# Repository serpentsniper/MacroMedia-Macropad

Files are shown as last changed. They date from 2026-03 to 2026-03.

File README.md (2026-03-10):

# MacroMedia

MacroMedia is a 9 key media macropad with a rotary encoder and an OLED display. It uses KMK firmware on CircuitPython and is built around the Seeed XIAO RP2040.

Built for the Hackpad YSWS through Hack Club Blueprint.

## Features:

* 3x3 key grid for media and productivity controls
* 128x32 OLED display showing an equaliser bars animation
* EC11 rotary encoder for volume control
* 3 layers: Media, DAW shortcuts, and System/Function keys
* Fully 3D printed case
* No LEDs — clean and simple build

## CAD Model:

The case is two pieces — a top plate and a bottom enclosure. Everything is held together with 4 M3x16mm screws and M3x5x4mm heatset inserts.

---

Case

---

The top plate is 1.5mm thick at the switch cutouts so MX switches clip in securely. The encoder shaft and OLED display window are cut into the top section above the key grid.

Made in Autodesk Inventor.
---

Top Case

---

Bottom Case

---

## PCB:

Designed in KiCad. 2-layer board, 59.5mm x 100mm.

---

### Schematic
Schematic

---

### PCB
PCB

---

* 3x3 switch matrix with COL2ROW diode configuration
* Diodes on the back layer, tucked between switch rows
* XIAO RP2040 mounted on the bottom center with USB-C accessible from the rear
* OLED header top-left, encoder top-right
* Ground pour on B.Cu

## Firmware Overview:

This macropad uses [KMK](https://github.com/KMKfw/kmk_firmware) firmware running on CircuitPython.

IMPORTANT NOTE: This macropad's firmware also includes the adafruit\_ssd1306 to interact with the OLED screen. This must be installed into the lib folder on the RP2040.

---

### OLED Animation (concept preview)
Animation

---

### Key Mapping

**Layer 0 — Media:**

|Prev|Play/Pause|Next|
|-|-|-|
|Stop|Mute|Vol Up|
|Layer 1|Layer 2|Vol Down|

**Layer 1 — DAW:**

|Undo|Redo|Save|
|-|-|-|
|Cut|Copy|Paste|
|\_\_|\_\_|\_\_|

**Layer 2 — System:**

|F13|F14|F15|
|-|-|-|
|F16|F17|F18|
|\_\_|\_\_|Reset|

**Encoder:** Volume up/down on Layer 0, zoom on Layer 1, brightness on Layer 2.

## BOM:

* 9x Cherry MX Switches
* 9x DSA Keycaps
* 9x 1N4148 DO-35 Diodes
* 1x EC11 Rotary Encoder
* 1x 0.91" 128x32 OLED Display (GND-VCC-SCL-SDA pin order)
* 1x Seeed XIAO RP2040
* 4x M3x16mm Screws
* 4x M3x5x4mm Heatset Inserts
* 1x 3D Printed Case (2 parts: top plate + bottom enclosure)

## Setup:

1. Flash CircuitPython from https://circuitpython.org/board/seeeduino\_xiao\_rp2040
2. Copy `main.py` to your `CIRCUITPY` drive
3. Copy `adafruit\_ssd1306.mpy` to the lib folder in your `CIRCUITPY` drive (accessible at https://github.com/adafruit/Adafruit\_CircuitPython\_SSD1306)

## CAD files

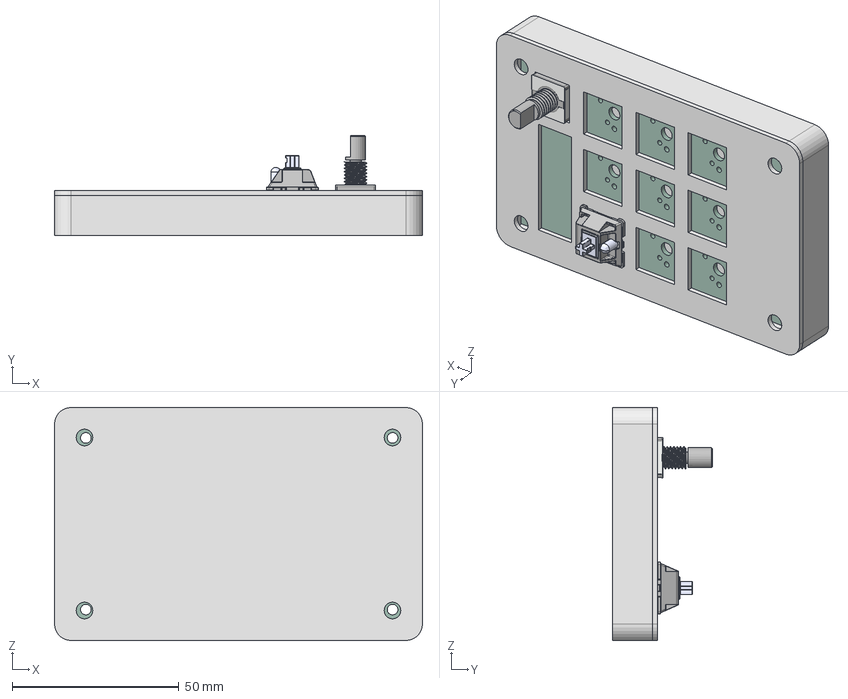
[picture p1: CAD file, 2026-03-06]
CAD/Complete_Hackpad.step
110.4 x 30.0 x 69.9 mm
top part
æè½¬ç¼ç å¨
MX Öá °´¼ü¡ä_¨¹ ___¡§1
MX ס סͥ¨¢¨¬_¡ §¡顧__
MXס ϞñLEDLEDLED
MXÖá ÖáÌå µ×²¿ ¦Ì¡ Á2__Ä¬ÈÏ_¨¢2____¨¨_
֫½ğ__Ĭɏ__¨¨_
D_DO-35_SOD27_P7.62mm_Horizontal x 9
hackpad_PCB

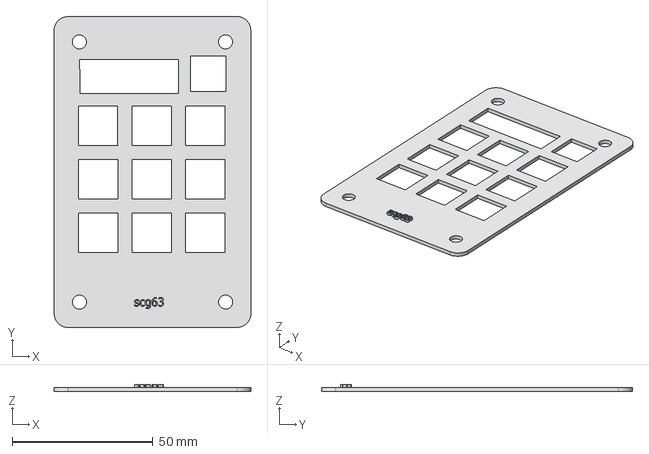
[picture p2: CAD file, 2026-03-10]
production/Top Part.step
69.9 x 110.4 x 2.50 mm

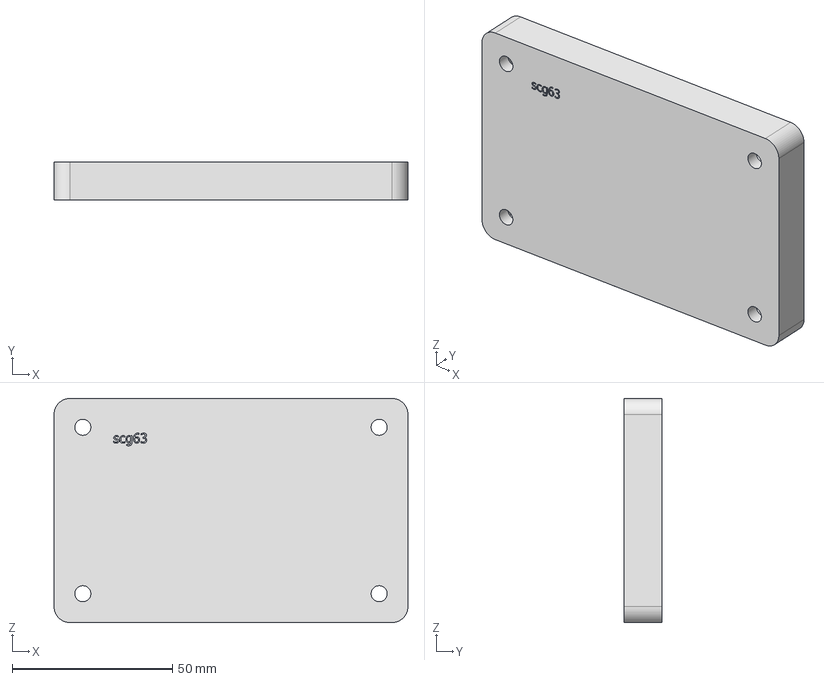
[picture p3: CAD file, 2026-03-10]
production/Bottom Part.step
110.4 x 12.0 x 69.9 mm

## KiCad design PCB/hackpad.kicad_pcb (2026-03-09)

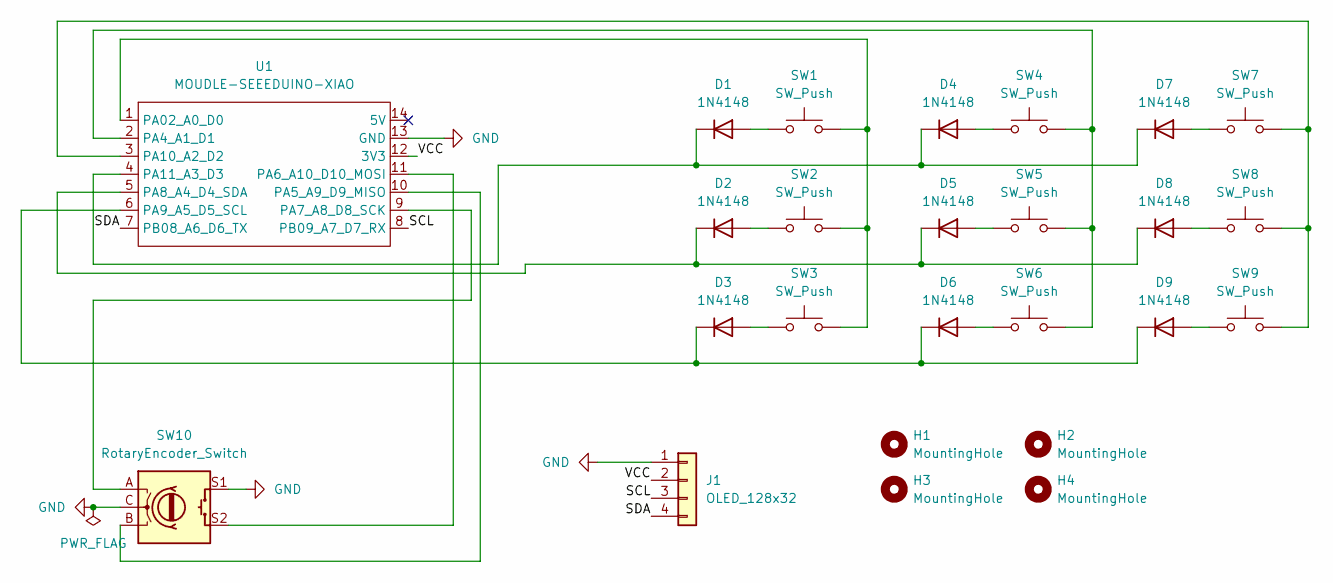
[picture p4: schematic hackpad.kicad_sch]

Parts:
D1, D2, D3, D4, D5, D6, D7, D8, D9: 1N4148; D_DO-35_SOD27_P7.62mm_Horizontal
H1, H2, H3, H4: MountingHole; MountingHole_3.2mm_M3
J1: OLED_128x32; SSD1306-0.91-OLED-4pin-128x32
SW1, SW2, SW3, SW4, SW5, SW6, SW7, SW8, SW9: SW_Push; SW_Cherry_MX_1.00u_PCB
SW10: RotaryEncoder_Switch; RotaryEncoder_Alps_EC11E-Switch_Vertical_H20mm
U1: MOUDLE-SEEEDUINO-XIAO; XIAO-Generic-Hybrid-14P-2.54-21X17.8MM

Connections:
/SCL: J1.3, U1.8 (PB09_A7_D7_RX)
/SDA: J1.4, U1.7 (PB08_A6_D6_TX)
/VCC: J1.2, U1.12 (3V3)
GND: J1.1, SW10.C, SW10.S1, U1.13 (GND)
unnamed: D1.2 (A), SW1.1
unnamed: D1.1 (K), D4.1 (K), D7.1 (K), U1.4 (PA11_A3_D3)
unnamed: D2.2 (A), SW2.1
unnamed: D2.1 (K), D5.1 (K), D8.1 (K), U1.5 (PA8_A4_D4_SDA)
unnamed: D3.2 (A), SW3.1
unnamed: D3.1 (K), D6.1 (K), D9.1 (K), U1.6 (PA9_A5_D5_SCL)
unnamed: D4.2 (A), SW4.1
unnamed: D5.2 (A), SW5.1
unnamed: D6.2 (A), SW6.1
unnamed: D7.2 (A), SW7.1
unnamed: D8.2 (A), SW8.1
unnamed: D9.2 (A), SW9.1
unnamed: SW1.2, SW2.2, SW3.2, U1.1 (PA02_A0_D0)
unnamed: SW4.2, SW5.2, SW6.2, U1.2 (PA4_A1_D1)
unnamed: SW10.B, U1.10 (PA5_A9_D9_MISO)
unnamed: SW10.S2, U1.11 (PA6_A10_D10_MOSI)
unnamed: SW10.A, U1.9 (PA7_A8_D8_SCK)
unnamed: SW7.2, SW8.2, SW9.2, U1.3 (PA10_A2_D2)

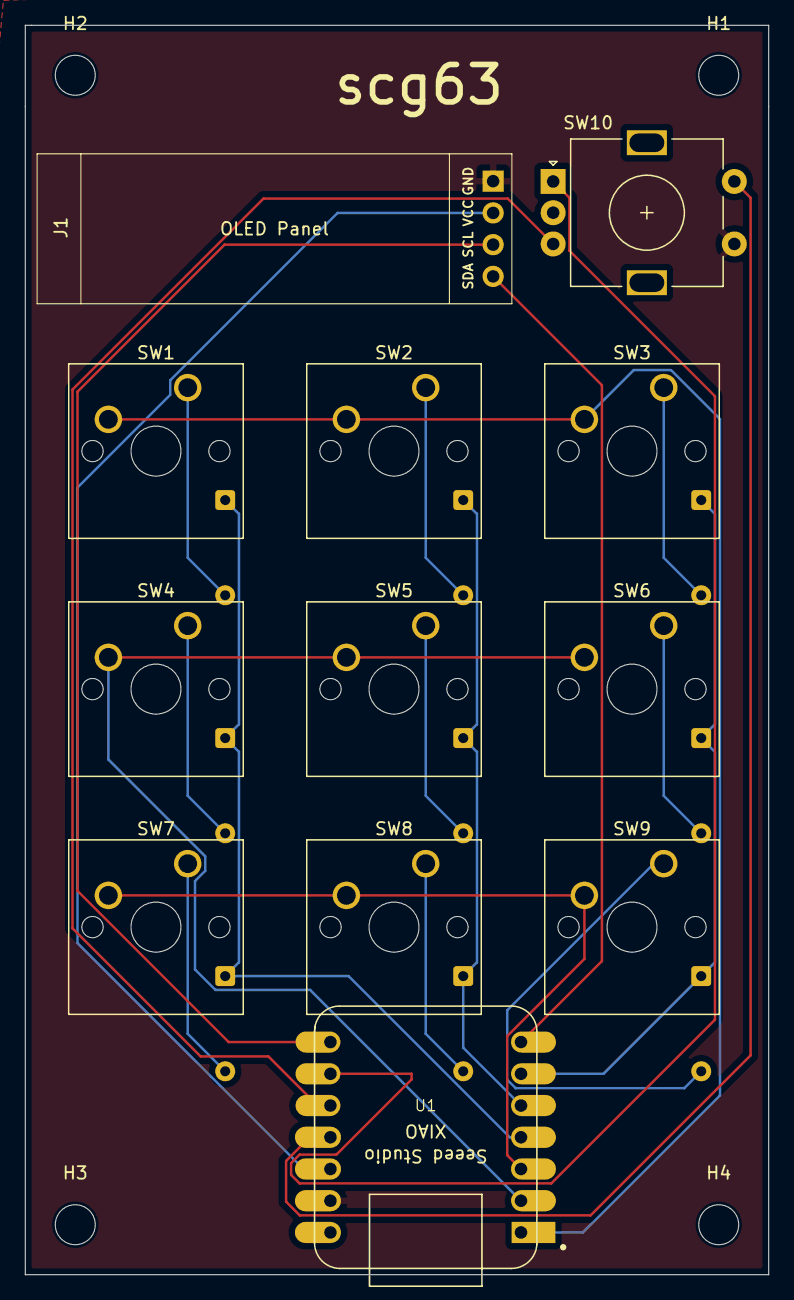
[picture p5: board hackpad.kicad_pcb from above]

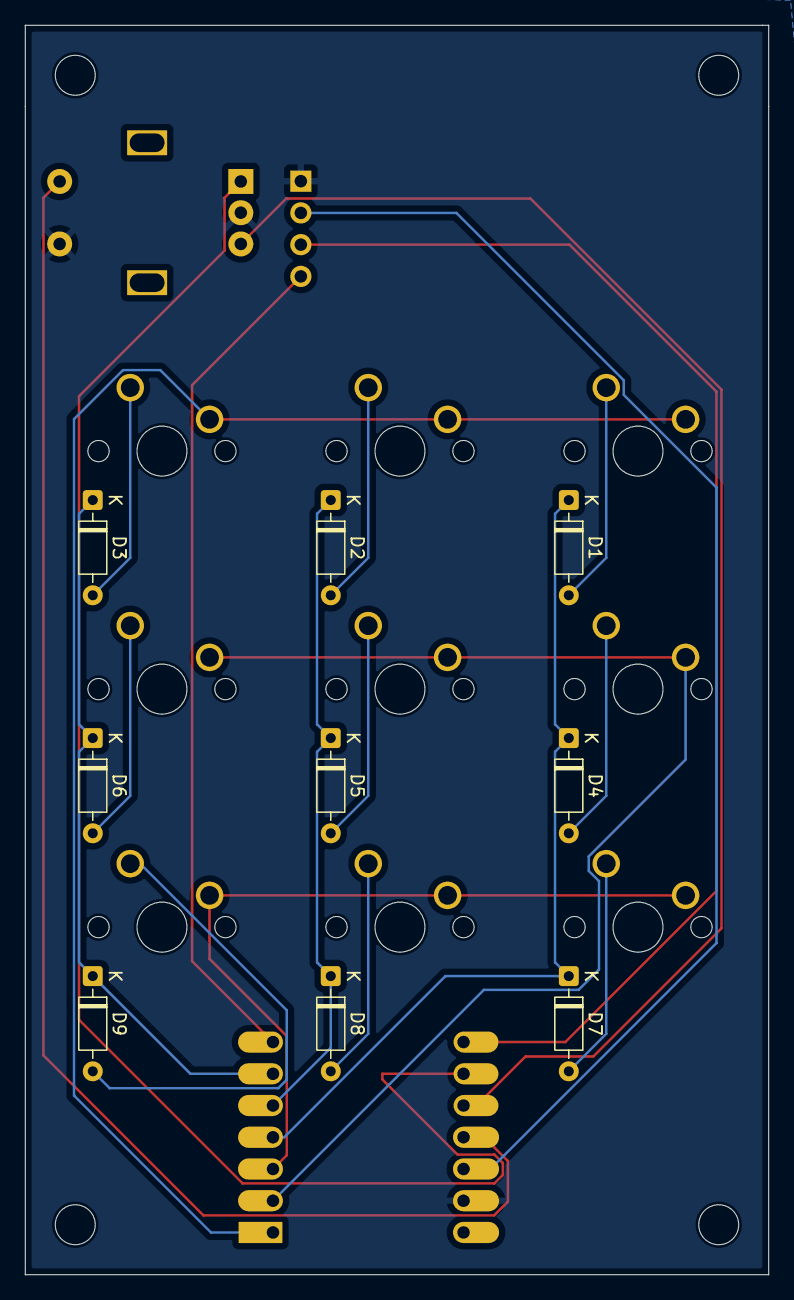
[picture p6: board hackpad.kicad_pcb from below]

Board: 2 copper layers, 59.5 x 100.0 mm, 25 parts (9 on the bottom side), 22 nets.

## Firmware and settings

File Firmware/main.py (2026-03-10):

"""
MelodyPad - 3x3 Music/Media Macropad Firmware
================================================
Hardware: Seeed XIAO RP2040 + 9 MX switches + 1 EC11 encoder + 0.91" OLED
Framework: KMK (CircuitPython)

Features:
  - 3-layer keymap (Media, DAW, System)
  - Rotary encoder for volume
  - Animated equalizer visualization on OLED
"""

import board
import busio
import digitalio
import random
import time

from kmk.kmk_keyboard import KMKKeyboard
from kmk.keys import KC
from kmk.scanners.keypad import MatrixScanner
from kmk.modules.layers import Layers
from kmk.modules.encoder import EncoderHandler
from kmk.modules.media_keys import MediaKeys
from kmk.extensions import Extension

# ============================================================
# OLED EQUALIZER EXTENSION
# ============================================================

import adafruit_ssd1306

class OledEqualizer(Extension):
    """Custom KMK extension that draws a randomized music
    equalizer animation on a 128x32 SSD1306 OLED."""

    def __init__(self, i2c, num_bars=16, bar_width=6, gap=2,
                 update_interval=0.05):
        self.i2c = i2c
        self.num_bars = num_bars
        self.bar_width = bar_width
        self.gap = gap
        self.update_interval = update_interval

        # Current and target heights for each bar (smooth animation)
        self.heights = [0] * num_bars
        self.targets = [0] * num_bars
        self.max_height = 30  # max bar height in pixels (screen is 32px)

        self.last_update = 0
        self.oled = None

    def on_runtime_enable(self, sandbox):
        self.oled = adafruit_ssd1306.SSD1306_I2C(128, 32, self.i2c)
        self.oled.fill(0)
        self.oled.show()
        self._new_targets()

    def on_runtime_disable(self, sandbox):
        if self.oled:
            self.oled.fill(0)
            self.oled.show()

    def during_bootup(self, sandbox):
        self.on_runtime_enable(sandbox)

    def before_matrix_scan(self, sandbox):
        """Called every scan cycle - update animation here."""
        now = time.monotonic()
        if now - self.last_update < self.update_interval:
            return
        self.last_update = now

        if not self.oled:
            return

        # Smoothly move current heights toward targets
        for i in range(self.num_bars):
            diff = self.targets[i] - self.heights[i]
            speed = max(1, abs(diff) // 3)
            if diff > 0:
                self.heights[i] = min(self.heights[i] + speed,
                                      self.targets[i])
            elif diff < 0:
                self.heights[i] = max(self.heights[i] - speed,
                                      self.targets[i])

        # Pick new targets when most bars have settled
        settled = sum(1 for i in range(self.num_bars)
                      if abs(self.heights[i] - self.targets[i]) <= 2)
        if settled > self.num_bars // 2:
            self._new_targets()

        self._draw()

    def after_matrix_scan(self, sandbox):
        pass

    def before_hid_send(self, sandbox):
        pass

    def after_hid_send(self, sandbox):
        pass

    def on_powersave_enable(self, sandbox):
        pass

    def on_powersave_disable(self, sandbox):
        pass

    def _new_targets(self):
        """Generate random target heights that look like a real
        equalizer - middle bars tend higher, adjacent bars
        are loosely correlated."""
        for i in range(self.num_bars):
            base = random.randint(3, self.max_height)

            # Middle bars tend taller (like a real audio spectrum)
            center = self.num_bars / 2
            dist_from_center = abs(i - center) / center
            boost = int((1.0 - dist_from_center * 0.4) * base)

            self.targets[i] = max(2, min(self.max_height,
                                         boost + random.randint(-4, 4)))

    def _draw(self):
        """Render equalizer bars to the OLED."""
        self.oled.fill(0)

        for i in range(self.num_bars):
            x = i * (self.bar_width + self.gap) + 1
            h = max(1, self.heights[i])

            # Bars grow upward from bottom of screen
            y_top = 31 - h
            y_bottom = 31

            # Draw filled bar
            for y in range(y_top, y_bottom + 1):
                for dx in range(self.bar_width):
                    px = x + dx
                    if 0 <= px < 128:
                        self.oled.pixel(px, y, 1)

            # Add horizontal gap lines for segmented look
            # (like the pink bars in the reference image)
            if h > 4:
                for seg_y in range(y_top + 2, y_bottom, 3):
                    for dx in range(self.bar_width):
                        px = x + dx
                        if 0 <= px < 128:
                            self.oled.pixel(px, seg_y, 0)

            # Floating peak dot above bar
            peak_y = max(0, y_top - 2)
            for dx in range(self.bar_width):
                px = x + dx
                if 0 <= px < 128:
                    self.oled.pixel(px, peak_y, 1)

        self.oled.show()


# ============================================================
# KEYBOARD SETUP
# ============================================================

keyboard = KMKKeyboard()

# Pins
COL_PINS = (board.D0, board.D1, board.D2)
ROW_PINS = (board.D3, board.D4, board.D5)

ENCODER_PIN_A = board.D9
ENCODER_PIN_B = board.D10

# Matrix
keyboard.matrix = MatrixScanner(
    cols=COL_PINS,
    rows=ROW_PINS,
    diode_orientation=digitalio.Direction.INPUT,
)

# Modules
layers = Layers()
encoder_handler = EncoderHandler()
media_keys = MediaKeys()
keyboard.modules = [layers, encoder_handler, media_keys]

# Encoder (no button)
encoder_handler.pins = (
    (ENCODER_PIN_A, ENCODER_PIN_B, None, False),
)

# OLED equalizer
i2c = busio.I2C(board.D7, board.D6)
equalizer = OledEqualizer(
    i2c=i2c,
    num_bars=16,           # number of bars across screen
    bar_width=6,           # pixel width per bar
    gap=2,                 # pixel gap between bars
    update_interval=0.06,  # seconds between frames (~16fps)
)
keyboard.extensions.append(equalizer)

# Layer keys
LYR1 = KC.MO(1)
LYR2 = KC.MO(2)

# Keymap
keyboard.keymap = [
    # Layer 0: Media Control
    # +----------+----------+----------+
    # |   Prev   | Play/Pse |   Next   |
    # +----------+----------+----------+
    # |   Stop   |   Mute   |  Vol Up  |
    # +----------+----------+----------+
    # |  Layer1  |  Layer2  |  Vol Dn  |
    # +----------+----------+----------+
    [
        KC.MPRV,   KC.MPLY,   KC.MNXT,
        KC.MSTP,   KC.MUTE,   KC.VOLU,
        LYR1,      LYR2,      KC.VOLD,
    ],

    # Layer 1: DAW Shortcuts
    [
        KC.LCTRL(KC.Z),  KC.LCTRL(KC.Y),  KC.LCTRL(KC.S),
        KC.LCTRL(KC.X),  KC.LCTRL(KC.C),  KC.LCTRL(KC.V),
        KC.TRNS,          KC.TRNS,          KC.TRNS,
    ],

    # Layer 2: System / F-Keys
    [
        KC.F13,    KC.F14,    KC.F15,
        KC.F16,    KC.F17,    KC.F18,
        KC.TRNS,   KC.TRNS,   KC.RESET,
    ],
]

# Encoder map (per layer)
encoder_handler.map = [
    ((KC.VOLD, KC.VOLU),),
    ((KC.LCTRL(KC.MINUS), KC.LCTRL(KC.EQUAL)),),
    ((KC.BRID, KC.BRIU),),
]

keyboard.go()

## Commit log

2026-03-06 Added final CAD
    [Complete_Hackpad.step]
2026-03-06 Added all final KiCAD files
    [hackpad.kicad_pcb, hackpad.kicad_sch]
2026-03-10 Uploaded CAD files for production
    [Bottom Part.step, Top Part.step]
